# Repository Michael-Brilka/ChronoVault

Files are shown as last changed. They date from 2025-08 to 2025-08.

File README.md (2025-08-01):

# Tracking Task Progress with a Proactive Video Recording System



## Abstract
Reliving past events is a crucial aspect of visual research, enabling deeper insights into both the sequence and context of actions. Ideally, a continuous recording would ensure that no moment is lost; however, this approach quickly becomes impractical due to the immense effort required to review and analyze large amounts of footage. To address this challenge, prior work has introduced devices equipped with sensors and cameras that automatically trigger recordings when predefined conditions are met. While this selective recording approach reduces unnecessary footage, it is limited to capturing only the present and lacks retrospective context, which is essential for analyzing complex scenarios. We introduce ChronoVault, an open-source framework designed for simple setup, configuration, and recording of retrospective videos. ChronoVault continuously monitors hardware- and software-signals, buffering a video-stream and saving said buffer, when specific conditions are detected. The system is built on the Raspberry Pi Zero 2, which supports camera integration and connectivity with peripheral devices. To evaluate ChronoVault we performed a user study. In it, participants were tasked to build a model out of building blocks and document the ends of certain subassembly tasks. Compared to an external reference camera, we reduce the footage amount, while retaining all relevant events.

## Material for reproducing/ appropriation
In the Work folder, you will find the code, 3D files for the case, and electronic schematics. Additionally, we provide an image of the entire operating system (OS) we used, which can be downloaded from [this link](https://uni-siegen.sciebo.de/s/Z9NccgHyLzWSwr3). The OS is configured to automatically launch into desktop mode.
The current username is "rpiPW123" and the password is "123". Please note: our software is deactivated in the OS image. To activate it, navigate to Desktop/ChronoVault/main.py and change line 126 to True. Important: The current size of the root partition is only 11.7 GB. The remaining space on the storage device is unallocated. You can increase the size of the root partition (Partition 2) using tools such as GParted.

## License
This project is licensed under the [Creative Commons Attribution-NonCommercial-ShareAlike 4.0 International License (CC BY-NC-SA 4.0)](https://creativecommons.org/licenses/by-nc-sa/4.0/).

You are free to share and adapt the material, as long as you:
- Give appropriate credit  
- Do not use it for commercial purposes  
- Distribute any modified content under the same license  

## Contact
Michael Brilka (michael.brilka@uni-siegen.de)

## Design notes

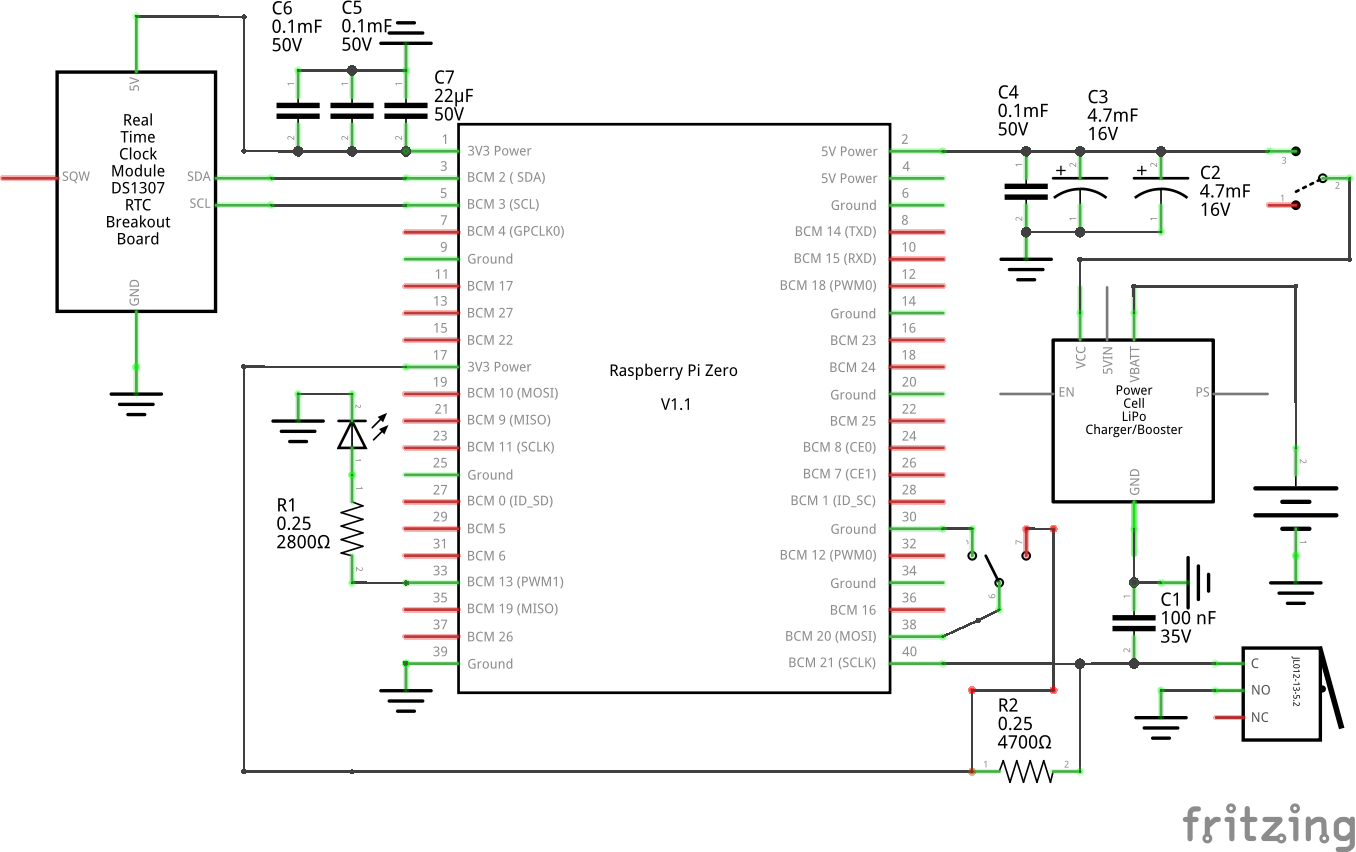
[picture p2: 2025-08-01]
Work/Electronics/Schematic_Complete.png

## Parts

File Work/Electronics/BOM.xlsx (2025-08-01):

Part | Quantity
Raspberry Pi Zero 2 W | 1
Raspberry Pi – Camera, 12MP, 75°, M12-Mount | 1
Waveshare – ws1132712 | 1
Raspberry Pi - Ribbon cable for camera, 20 cm | 1
snap action switch | 2
DEBO3 3.7LI 1.0A – Li ion charger board | 1
On / off Switch | 2
pin header 2*1 | 2
pin header 4*1 | 1
pin sockets 2*1 | 2
pin sockets 4*1 | 1
100 nF | 1
22 uF | 1
100 uF | 3
4700 uF | 2
Battery 1500 mAh | 1
1k Resitor | 1
Raspberry Pi - Real-Time-Clock-Modul (RTC), DS3231 | 1
Green led | 1
4,7 k resistor | 1

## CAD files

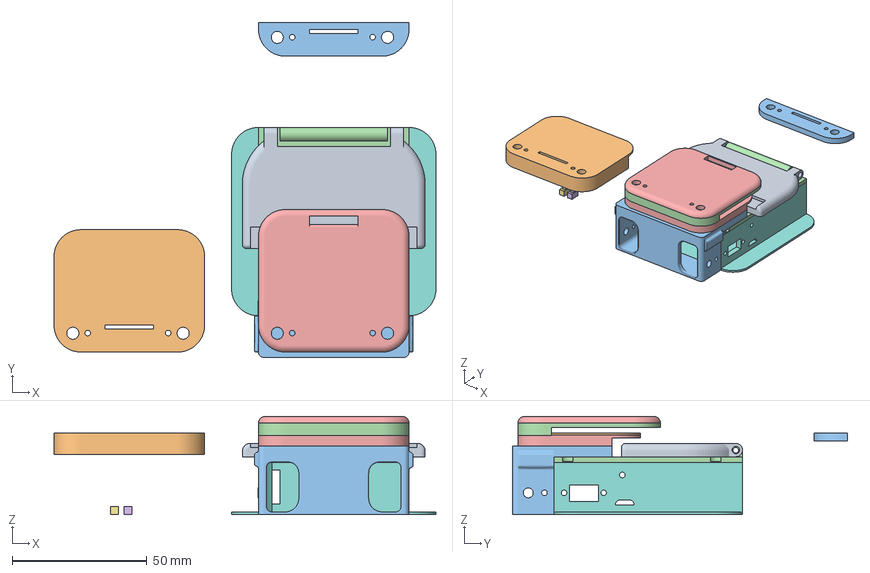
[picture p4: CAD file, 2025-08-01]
Work/Case/ChronoVault.3mf
142.0 x 124.5 x 36.5 mm
addional Link (optional) (1)
addional Link (optional)
additional spacer (optional) insert between camera cable guide and flapholder
camera cable guide
camera plate
camera spacer (1)
camera spacer
case
flap
flapholder
lanyard
lid
modified flapholder for lanyard

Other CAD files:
Work/Case/ChronoVault.f3d

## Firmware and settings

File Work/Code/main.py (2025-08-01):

import time
from multiprocessing import Process
import yaml
import os
import threading
import ffmpeg
from picamera2 import Picamera2
from picamera2.encoders import Quality, H264Encoder
from picamera2.outputs import CircularOutput

import RPi.GPIO as GPIO

import queue




class eventRecorder:

    def __init__(self, settingsFile):
        self.picamera = Picamera2()

        self.captureQueue = queue.Queue(10)
        self.convertQueue = queue.Queue(10)
        settings = self.Settings(settingsFile)
        #check if folders exist
        captureFolder = os.path.isdir(settings.captureFolder)
        
        if(not captureFolder):
            os.mkdir(settings.captureFolder)
            
        self.settings = settings

    class Settings:
        def __init__(self, file: str):
            with open(file, 'r') as stream:
                self.settings = yaml.safe_load(stream)

            self.captureFolder = self.settings["project"]["capture_Location"]
            self.id = self.settings["project"]["id"]

    def record(self, buffersize : int, additionalRecording : int = 0):
        
        
        vconfig = self.picamera.create_video_configuration()
        self.picamera.configure(vconfig)
    
        
        while True: 
            encoder = H264Encoder(10000000)
            encoder.output = CircularOutput(buffersize = buffersize, outputtofile=False)  
            
            self.picamera.start()
            self.picamera.start_encoder(encoder)
            
            #wait for event
            t=self.captureQueue.get(block=True)

            filename = self.settings.id+"_"+str(int(t)) + ".h264"
            file = os.path.join(self.settings.captureFolder, filename)
            encoder.output.fileoutput = file
            time.sleep(0.1)
            #start_and record
            encoder.output.start()
            
            #record for n more seconds
            if(additionalRecording > 0):
                time.sleep(additionalRecording)
                
            #stop recording
            encoder.output.stop()
            print("end recording")
            self.picamera.stop_encoder()
            self.picamera.stop()


    def saveEventHW(self,pin, afterCapture = None ):
       
        GPIO.setmode(GPIO.BOARD)
        GPIO.setup(pin, GPIO.IN, pull_up_down=20)

        while True:
            #button press: wait till falling edge
            GPIO.wait_for_edge(pin, GPIO.FALLING)
            
            t = time.time()
            self.captureQueue.put(t)

            #execute in parallel
            if(afterCapture != None):
                afterCapture(t)
            
            
        
    def saveEventSW(self, trigger: queue.Queue, afterCapture = None):
        while True:
            trigger.get(block= True)
            t = time.time()
            self.captureQueue.put(t)

            #execute in parallel
            if(afterCapture != None):
                afterCapture(t)

     def createSaveEventHW(self, pin , afterCapture = None, triggerQueue: queue.Queue = None):
        #triggerQueue unused, added to support faster switching between HW and SW saveEvent
        thread = threading.Thread(target=self.saveEventHW , args= (pin, afterCapture))
        thread.start()

    def createSaveEventSW(self, triggerQueue: queue.Queue, afterCapture = None, pin = None):
        #pin unused, added to support faster switching between HW and SW saveEvent
        thread = threading.Thread(target=self.saveEventSW , args= (triggerQueue, afterCapture))
        thread.start()

    def start(self, buffersizeFrames, additionalRecording):
        thread = threading.Thread(target=self.convert)
        thread.start()
        self.record(buffersize=buffersizeFrames, additionalRecording= additionalRecording)

def main():
#replace with your setup
    modeSwitch = 38
    statusLED = 33
    
    
    GPIO.setmode(GPIO.BOARD)
    GPIO.setup(modeSwitch, GPIO.IN)
    GPIO.setup(statusLED, GPIO.OUT)
    
    if(False): # The following lines are disabled for publishing purposes. Reactivate them for usage
        #replace for your setup
        
        if(GPIO.input(modeSwitch)==0):
            recorder = eventRecorder("Desktop/ChronoVAult/config.yaml")
        
            GPIO.output(statusLED,1)
            recorder.createSaveEventHW(pin = 40, afterCapture= timestamp )
            try:
                recorder.start(buffersizeFrames=500, additionalRecording= 3)
                while(True):
                    pass
            except:
                GPIO.output(statusLED,0)#deactivate led if an error occours

        else:
            print("Fileserver")
            os.system("sudo nmcli con up FileServer")
            while(True):
            	pass
        
        
        
def timestamp(time):
    print("trigger")
    f = open("time.csv", "a")
    #write in csv
    f.write(str(time))
    f.write(",\n")
    f.flush()

if __name__ == '__main__':
    main()
